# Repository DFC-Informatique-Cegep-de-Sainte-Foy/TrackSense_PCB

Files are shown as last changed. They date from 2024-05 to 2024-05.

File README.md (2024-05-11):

# TrackSense PCB

## Un protoype expérimental pour le projet [TrackSense](https://github.com/DFC-Informatique-Cegep-de-Sainte-Foy/TrackSense)

**:warning: <span style="color:red">Avertissement: ce design n'a pa été ni contruit ni testé. Ce dépôt n'offre aucune garantie quant au fonctionnement du prototype. Procédez à la fabrication à vos risques.</span>**

Créé avec le logiciel open source gratuit [KiCad V8.0.0](https://gitlab.com/kicad)

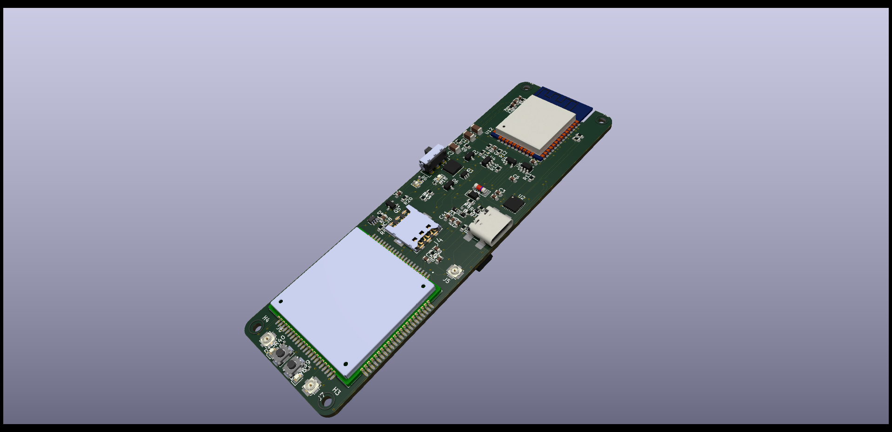
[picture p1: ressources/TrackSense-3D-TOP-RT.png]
Vue dessus

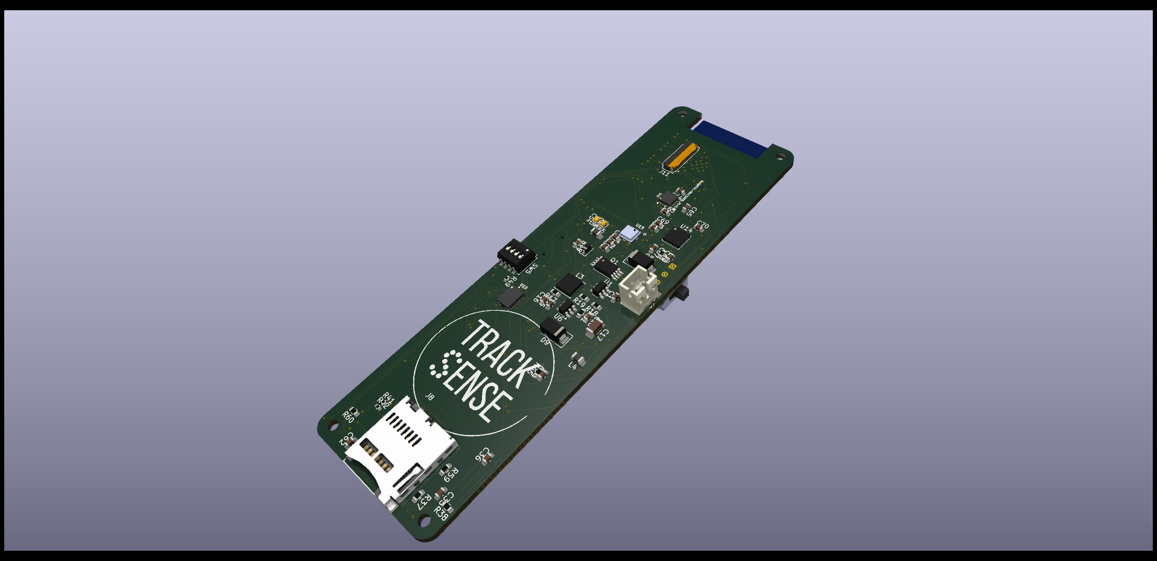
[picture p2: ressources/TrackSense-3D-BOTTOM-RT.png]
Vue dessous


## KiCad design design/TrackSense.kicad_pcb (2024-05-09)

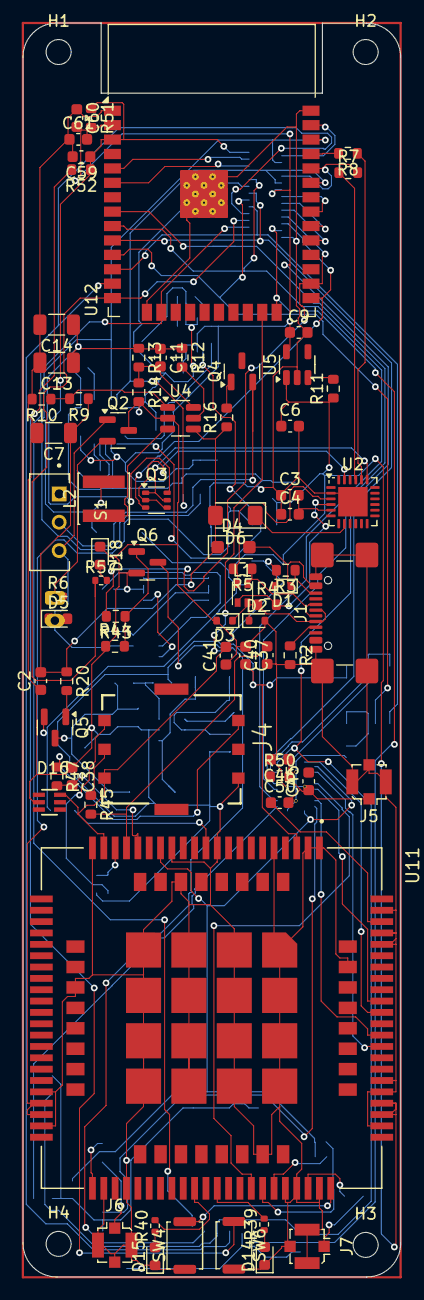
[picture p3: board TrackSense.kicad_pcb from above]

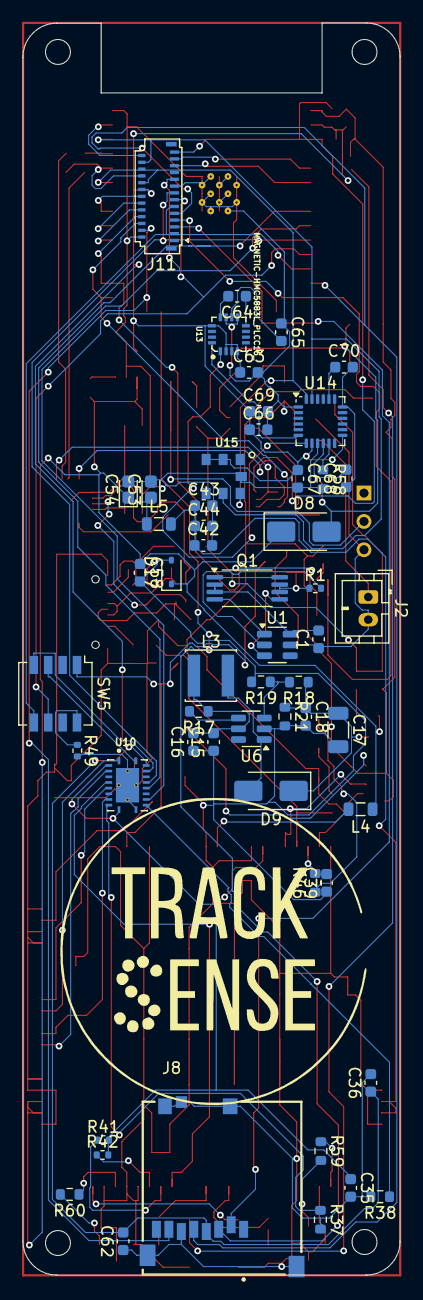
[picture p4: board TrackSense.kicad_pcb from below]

Board: 2 copper layers, 33.3 x 110.5 mm, 132 parts (54 on the bottom side), 107 nets.

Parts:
C1: 1nF; C_0603_1608Metric
C2, C4, C43, C44: 10uF; C_0603_1608Metric
C3: 100uF; C_0603_1608Metric
C6, C9, C35, C36, C46, C62: 100nF; C_0603_1608Metric
C7, C13, C14, C17: 22uF_10V; C_1206_3216Metric
C11: 47pF; C_0603_1608Metric
C15, C61: 10u; C_0603_1608Metric
C16: 1uf; C_0603_1608Metric
C18, C37, C41, C58: 0.1uF; C_0603_1608Metric
C38, C39, C40: 22uF; C_0603_1608Metric
C42, C59: 1uF; C_0603_1608Metric
C45, C50: 33pF; C_0603_1608Metric
C53, C54: 100uF; CP_EIA-1608-08_AVX-J
C60, C63, C66, C67, C68, C69: 0u1f; C_0603_1608Metric
C64: 220uf; C_0603_1608Metric
C65: 4.7uf; C_0603_1608Metric
C70: 2200pf; C_0603_1608Metric
D1, D2, D3: LESD5D5.0CT1G; D_SOD-523
D4: STPST1H100ZFY; D_SOD-123F
D5: YELLOW; LED_0603_1608Metric
D6: LL4148; D_MiniMELF
D8, D9: SS34; D_SMA
D14, D15: RED; LED_0603_1608Metric
D16: SMF05C; SOT65P210X110-6N
D17: PESDHC3D3V3U; D_SOD-323
D18: BLUE; LED_0603_1608Metric
H1, H2, H3, H4: MountingHole; MountingHole_2.2mm_M2_ISO7380
J1: C2765186; USB_C_Receptacle_GCT_USB4110
J2: Conn_01x02_Socket; JST_PH_B2B-PH-K_1x02_P2.00mm_Vertical
J4: SIM_Card; GCT_SIM8051-6-0-14-00-X-REVD
J5: GNSS_Coaxial_Small; U.FL_Molex_MCRF_73412-0110_Vertical
J6: MAIN_Coaxial_Small; U.FL_Molex_MCRF_73412-0110_Vertical
J7: AUX_Coaxial_Small; U.FL_Molex_MCRF_73412-0110_Vertical
J8: MEM2052-00-195-00-A_REVA; GCT_MEM2052-00-195-00-A_REVA
J11: Conn_01x28; Hirose_FH26-27S-0.3SHW_2Rows-27Pins-1MP_P0.60mm_Horizontal
L1: L_Ferrite_Coupled_1423; L_CommonModeChoke_Coilcraft_0805USB
L2: 1.5uH-DCR<0.1R-3A; L_Sunlord_SWPA4010S
L3: 4.7uH/3A; L_Sunlord_SWPA4010S
L4, L5: 100MHz 220ohm; L_0805_2012Metric
Q1: FS8205A; TSSOP-8_4.4x3mm_P0.65mm
Q2: AO3400A; SOT-23
Q3: UMH3N; SOT-363_SC-70-6
Q4, Q5: AO3401A; SOT-23
Q6: MMBT3904; SOT-23
R1: 1k; R_0402_1005Metric
R2, R3: 5.1k; R_0603_1608Metric
R4, R5: 10; R_0603_1608Metric
R6: 10k; R_0402_1005Metric
R7, R8: 470; R_0603_1608Metric
R9, R10, R21: 100K; R_0603_1608Metric
R11, R12, R17: 10K; R_0603_1608Metric
R13, R18: 120K_1%; R_0603_1608Metric
R14, R19: 20K_1%; R_0603_1608Metric
R16, R20: 100R; R_0603_1608Metric
R37, R38: 47k; R_0603_1608Metric
R39, R40: 390R; R_0402_1005Metric
R41, R42, R49: 10K; R_0402_1005Metric
R43: 4.7K; R_0603_1608Metric
R44: 47K; R_0603_1608Metric
R45, R46, R47, R52: 22R; R_0603_1608Metric
R50, R59, R60: 0R; R_0603_1608Metric
R51: 10k; R_0603_1608Metric
R57: 1K; R_0402_1005Metric
R58: 1k; R_0603_1608Metric
S1: EG1270; SW_EG1270
SW4: BOOT_CFG; SW_Push_SPST_NO_Alps_SKRK
SW5: SW_DIP_x04; SW_DIP_SPSTx04_Slide_Copal_CHS-04A_W5.08mm_P1.27mm_JPin
SW6: RESET; SW_Push_SPST_NO_Alps_SKRK
U1: WSTDW01; SOT-23-6
U2: CP2104; QFN-24-1EP_4x4mm_P0.5mm_EP2.6x2.6mm
U4: JW5222; SOT-23-6
U5: ME6217; SOT-23-5
U6: TCS9208; SOT-23-6
U10: TXB0108RGYR; IC_TXB0108RGYR
U11: SIM7600G; IC_SIM7600G
U12: ESP32-WROVER-B; ESP32-WROOM-32
U13: MAGNETIC-HMC5883L_PLCC16_; PLCC16-0.5-3X3MM
U14: MPU-6050; InvenSense_QFN-24_4x4mm_P0.5mm
U15: PRESSURE-BMP180_LGA7_; LGA7-1.5-3.8X3.6MM

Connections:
AUX_ANT: R60.1, U11.59 (AUX_ANT)
D+: J1.A6 (D+), J1.B6 (D+), L1.2, R5.1
D-: D2.1 (A1), D3.1 (A1), J1.A7 (D-), J1.B7 (D-), L1.1, R4.1
DM: L1.4, R4.2, U2.4 (D-)
DP: L1.3, R5.2, U2.3 (D+)
DTR: Q3.2 (B1), Q3.4 (E2), U2.23 (~DTR)
DVDD4V2: C6.1, C53.1, C54.1, C58.1, D8.1 (K), D17.1 (K), L4.1, L5.1, Q5.2 (S), R11.1, U5.1 (VIN), U11.62 (VBAT), U11.63 (VBAT)
FLIGHTMODE: U10.5 (A4), U11.54 (FLIGHTMODE)
G2: Q1.5, U1.3 (CO)
GND: C2.1, C3.1, C4.1, C6.2, C7.2, C9.2, C13.2, C14.2, C15.1, C16.1, C17.2, C18.2, C35.2, C36.2, C37.1, C38.1, C39.1, C40.1, C41.1, C42.2, C43.2, C44.2, C45.2, C46.2, C53.2, C54.2, C58.2, C59.2, C60.1, C61.1, C62.1, C63.2, C65.1, C66.2, C67.2, C68.1, C69.2, C70.2, D1.2 (A2), D2.2 (A2), D3.2 (A2), D14.1 (K), D15.1 (K), D16.2, D17.2 (A), D18.1 (K), J1.A1 (GND), J1.A12 (GND), J1.B1 (GND), J1.B12 (GND), J1.S1 (SHIELD), J4.5 (GND), J5.2 (Ext), J6.2 (Ext), J7.2 (Ext), J8.G1 (SHIELD_GND), J8.G2 (SHIELD_GND), J8.G3 (SHIELD_GND), J8.G4 (SHIELD_GND), J8.P6 (VSS), J8.P9 (CD_PIN), J11.2, J11.17, Q1.6, Q1.7, Q2.3 (D), Q6.2 (E), R1.1, R2.2, R3.2, R10.2, R14.2, R19.2, R21.2, R37.2, R38.2, R44.1, R49.2, R58.2, SW4.1, SW6.2, U2.2 (GND), U2.25 (GND), U4.2 (GND), U5.2 (VSS), U6.2 (GND), U10.11 (GND), U10.21 (EXP), U10.21_1 (EXP), U10.21_2 (EXP), U10.21_3 (EXP), U10.21_4 (EXP), U11.1 (GND), U11.2 (GND), U11.5 (GND), U11.10 (GND), U11.14 (GND), U11.37 (GND), U11.40 (GND), U11.41 (GND), U11.43 (GND), U11.57 (GND), U11.58 (GND), U11.60 (GND), U11.61 (GND), U11.64 (GND), U11.65 (GND), U11.77 (GND), U11.78 (GND), U11.80 (GND), U11.81 (GND), U11.93 (GND), U11.98 (GND), U11.110 (GND), U11.118 (GND), U11.120 (GND), U11.121 (GND), U11.122 (GND), U11.123 (GND), U11.124 (GND), U11.125 (GND), U11.126 (GND), U11.127 (GND), U11.128 (GND), U11.129 (GND), U11.130 (GND), U11.131 (GND), U11.132 (GND), U11.133 (GND), U11.134 (GND), U11.135 (GND), U12.1 (GND), U12.15 (GND), U12.38 (GND), U12.39 (GND), U13.9 (9(GND)), U13.11 (11(GND)), U14.1 (CLKIN), U14.9 (AD0), U14.18 (GND), U15.7 (GND)
GNSS_ANT: C50.1, U11.79 (GNSS_ANT)
GPIO26: SW5.3, U10.20 (B1)
GPIO27: SW5.4, U10.18 (B2)
IO0: J11.6, Q3.3 (C2), U12.25 (IO0)
IO2: J8.P7 (DAT0), J11.4, U12.24 (IO2)
IO4: J11.8, R43.2, U12.26 (IO4)
IO5: J11.10, U12.29 (IO5)
IO12: J11.7, R57.1, U12.14 (IO12)
IO13: J8.P2 (CD/DAT3), J11.5, U12.16 (IO13)
IO14: J8.P5 (CLK), J11.9, U12.13 (IO14)
IO15: J8.P3 (CMD), J11.3, U12.23 (IO15)
IO18: J11.12, U12.30 (IO18)
IO19: J11.14, U12.31 (IO19)
IO21: J11.18, U12.33 (IO21), U14.24 (SDA), U15.6 (SDA)
IO22: J11.24, U12.36 (IO22), U14.23 (SCL), U15.5 (SCL)
IO23: J11.26, U12.37 (IO23)
IO25: J11.15, U10.16 (B4), U12.10 (IO25)
IO26: J11.13, SW5.6, U12.11 (IO26)
IO27: J11.11, SW5.5, U12.12 (IO27)
IO32: J11.21, U10.15 (B5), U12.8 (IO32)
IO33: J11.19, U10.13 (B7), U12.9 (IO33)
IO34: J11.23, U12.6 (IO34)
MAIN_ANT: R59.1, U11.82 (MAIN_ANT)
unnamed: D1.1 (A1), D4.2 (A), J1.A4 (VBUS), J1.A9 (VBUS), J1.B4 (VBUS), J1.B9 (VBUS)
unnamed: D5.2 (A), R6.2
unnamed: D6.1 (K), U2.8 (VBUS)
unnamed: D9.2 (A), L3.2, U6.1 (SW)
unnamed: D14.2 (A), R39.1
unnamed: D15.2 (A), R40.1
unnamed: D18.2 (A), R57.2
unnamed: J1.A5 (CC1), R2.1
unnamed: J1.B5 (CC2), R3.1
unnamed: J2.1, Q2.2 (S), R6.1
unnamed: J4.3 (CLK), R46.1
unnamed: J4.7 (I/O), R47.1
unnamed: J4.2 (RST), R45.1
unnamed: C45.1, C46.1, C50.2, J5.1 (In), R50.2
unnamed: J6.1 (In), R59.2
unnamed: J7.1 (In), R60.2
unnamed: Q1.1, Q1.8
unnamed: Q4.1 (G), R16.2
unnamed: Q5.1 (G), R20.2
unnamed: Q6.1 (B), R43.1, R44.2
unnamed: R49.1, SW5.8
unnamed: R52.2, SW6.1
unnamed: Q1.4, U1.1 (DO)
unnamed: R1.2, U1.2 (VM)
unnamed: R8.1, U2.20 (RXD)
unnamed: R7.1, U2.21 (TXD)
unnamed: R9.2, R10.1, U4.1 (EN)
unnamed: C11.2, R13.2, R14.1, U4.6 (FB)
unnamed: R12.2, U4.5 (PG)
unnamed: L2.1, U4.3 (SW)
unnamed: R11.2, U5.3 (CE)
unnamed: R17.2, U6.4 (EN)
unnamed: R18.2, R19.1, U6.3 (FB)
unnamed: R37.1, U10.9 (A8)
unnamed: R38.1, U10.12 (B8)
unnamed: SW4.2, U11.85 (BOOT_CFG0/USB_BOOT)
unnamed: R39.2, U11.51 (NETLIGHT)
unnamed: L4.2, U11.11 (USB_VBUS)
unnamed: C64.1, U13.8 (8(SETP))
unnamed: C65.2, U13.10 (10(C1))
unnamed: C64.2, U13.12 (12(SETC))
unnamed: C70.1, U14.20 (CPOUT)
unnamed: R58.1, U14.11 (FSYNC)
unnamed: C68.2, U14.10 (REGOUT)
PWRKEY: C37.2, Q6.3 (C), SW5.1, U11.3 (~PWRKEY)
RST/EN: C59.1, J11.27, Q3.6 (C1), R51.1, R52.1, U12.3 (EN)
RTS: Q3.1 (E1), Q3.5 (B2), U2.19 (~RTS)
SCL: R41.1, U11.55 (SCL)
SDA: R42.1, U11.56 (SDA)
SIM_CLK: C39.2, R46.2, U11.19 (USIM_CLK)
SIM_IO: C38.2, R47.2, U11.17 (USIM_DATA)
SIM_RST: C40.2, R45.2, U11.18 (USIM_RST)
STATUS: R40.2, U11.49 (STATUS)
S_VN/39: J11.25, U12.5 (SENSOR_VN)
U0RXD: J11.20, R7.2, U12.34 (RXD0/IO3)
U0TXD: J11.22, R8.2, U12.35 (TXD0/IO1)
UART_DTR: U10.6 (A5), U11.72 (DTR)
UART_RI: U10.8 (A7), U11.69 (RI)
UART_RXD: U10.3 (A2), U11.68 (RXD)
UART_TXD: U10.1 (A1), U11.71 (TXD)
VBAT: C15.2, C16.2, L3.1, R17.1, U6.5 (IN)
VBAT-: C1.2, Q1.2, Q1.3, U1.6 (VSS)
VBUS: C2.2, C7.1, D4.1 (K), D6.2 (A), R9.1, R16.1, R20.1, U4.4 (VIN)
VCC3V3: C9.1, C36.1, C60.2, C61.2, C62.2, C63.1, C66.1, C67.1, C69.1, J8.P4 (VDD), J11.1, J11.16, R51.2, U5.5 (VOUT), U10.19 (VCCB), U12.2 (VDD), U13.2 (2(VDD)), U13.4 (4(S1)), U13.13 (13(VDDIO)), U14.8 (VLOGIC), U14.13 (VDD), U15.2 (VDD), U15.3 (VDDIO)
VCC_4V2: C11.1, C13.1, C14.1, D8.2 (A), L2.2, R12.1, R13.1
VCC_BAT: C1.1, D5.1 (K), J2.2, Q2.1 (G), S1.3, U1.5 (VDD)
VCC_MAIN: C42.1, C43.1, C44.1, L5.2, U11.38 (VBAT), U11.39 (VBAT)
VCC_UART: C3.2, C4.2, U2.5 (VIO)
VDD_1V8: C35.1, R41.2, R42.2, U10.2 (VCCA), U10.10 (OE), U11.15 (VDD_1V8)
VDD_4V2: C17.1, C18.1, D9.1 (K), Q5.3 (D), R18.1, R21.1
VSIM: C41.2, D16.6, J4.1 (VCC), U11.20 (USIM_VDD)
V_BAT: Q4.2 (S), S1.2
XCL: U13.1 (1(SCL)), U14.7 (AUX_CL)
XDA: U13.16 (16(SDA)), U14.6 (AUX_DA)
